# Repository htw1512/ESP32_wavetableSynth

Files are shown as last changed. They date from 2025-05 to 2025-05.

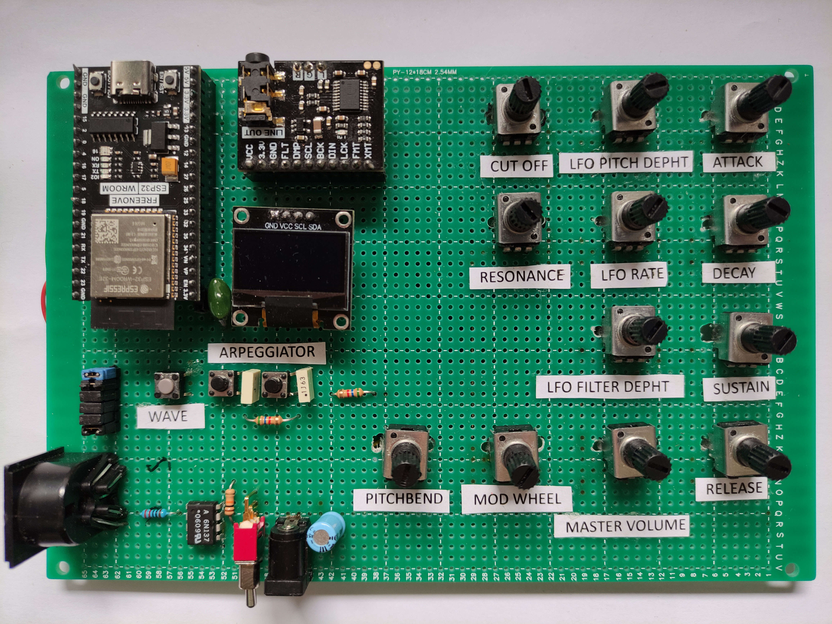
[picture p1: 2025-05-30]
Bilder/synth32.jpg

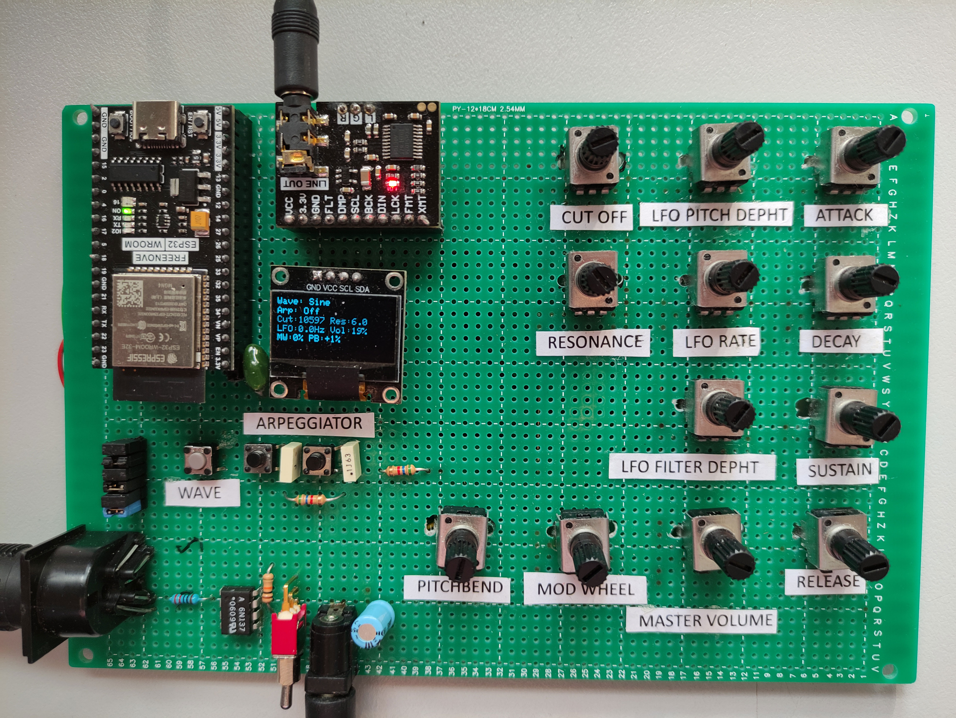
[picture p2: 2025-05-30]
Bilder/synth32_Betrieb.jpg

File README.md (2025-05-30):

# ESP32-S3 Polyphoner Wavetable-Synthesizer

Dieser vielseitige polyphone Synthesizer basiert auf dem ESP32-S3 Mikrocontroller und bietet eine breite Palette an Klangerzeugungsmöglichkeiten. Er verfügt über eine umfangreiche Sammlung an Wavetables, eine vollständige ADSR-Hüllkurve, ein State-Variable-Filter, einen modulierbaren LFO und einen komplexen Arpeggiator mit zahlreichen Modi, einschließlich Optionen für synchronisierte Tonika-Noten. Die Steuerung erfolgt über Potentiometer und Taster, mit visueller Rückmeldung über ein OLED-Display. MIDI-Eingabe wird über eine traditionelle 5-Pol-DIN-Buchse realisiert.

## Kernmodule des Synthesizers

*   **Oszillatoren**:
    *   Bis zu 51 verschiedene digital generierte Wellenformen pro Stimme.
    *   Auswahl umfasst klassische Formen (Sinus, Sägezahn, Rechteck, Dreieck), Pulsbreitenvarianten, Sync-Sounds, Formant-ähnliche Wellen und diverse experimentelle sowie perkussive und klavierähnliche Texturen.
    *   Auswahl der Wellenform über einen dedizierten Taster.
*   **Hüllkurve**:
    *   Eine ADSR-Hüllkurve (Attack, Decay, Sustain, Release) pro Stimme zur Formung der Lautstärke.
    *   Parameter steuerbar über dedizierte Potentiometer.
*   **Filter**:
    *   Ein globales State-Variable-Filter (SVF), dessen Tiefpass-Ausgang genutzt wird.
    *   Cutoff-Frequenz und Resonanz sind über Potentiometer regelbar.
*   **LFO (Low-Frequency Oscillator)**:
    *   Ein globaler LFO (Sinuswelle).
    *   Kann die Tonhöhe (Pitch) und/oder die Filter-Cutoff-Frequenz modulieren.
    *   LFO-Rate und die Modulationstiefe für Filter und Pitch (letztere oft in Kombination mit einem Modulationsrad-Poti) sind über Potentiometer einstellbar.
*   **Arpeggiator**:
    *   Umfangreicher Arpeggiator mit diversen Modi und Steuerungen:
        *   **Grund-Pattern**: Up, Down, Up/Down (mit korrekter Notenwiederholung), Random.
        *   **Oktav-Pattern**: Oct Up (spielt Pattern über mehrere Oktaven aufwärts), Oct Down (abwärts).
        *   **Chord-Modus**: Spielt alle gehaltenen Noten gleichzeitig im Arp-Rhythmus.
        *   **Played Order**: Spielt Noten in der Reihenfolge ihres Anschlags.
        *   **Geschwindigkeits-Modi**: Doppel- und Halbgeschwindigkeitsvarianten für Up, Down und Up/Down Pattern.
        *   **Tonika-Modi**: Varianten von Up, Down, Up/Down und Random, bei denen zusätzlich die tiefste gehaltene Note (Tonika) auf jedem Arp-Step mitgespielt wird.
    *   Steuerung über Taster für An/Aus und Moduswahl.
*   **MIDI-Eingang**:
    *   Empfang von MIDI-Daten (Note On, Note Off, Velocity) über eine traditionelle 5-Pol-DIN-Buchse, die über eine Optokoppler-Schaltung (6N137) an einen Hardware-Serial-Port des ESP32-S3 angebunden ist.
*   **Steuerung & Interaktion**:
    *   Analoge Potentiometer für Echtzeitkontrolle der meisten Syntheseparameter.
    *   Dedizierte Taster für Wellenformauswahl, Arp An/Aus und Arp-Moduswahl.
    *   Pitchbend- und Modulationsrad-Funktionalität über Potentiometer.
*   **Display**:
    *   0,96 Zoll OLED-Display (SSD1306-basiert, 128x64 Pixel) zur Anzeige der aktuellen Parameter, angebunden über I2C (SDA, SCL Pins).
*   **Audioausgabe**:
    *   Stereo-Audioausgabe über einen externen PCM5102A Digital-Analog-Wandler (DAC), der über die I2S-Schnittstelle des ESP32-S3 angesteuert wird.

## Hardware-Aufbau

*   **Mikrocontroller-Board**: Freenove ESP32-S3-WROOM-1 Development Board (oder ein vergleichbares ESP32-S3 Board).
*   **Digital-Analog-Wandler (DAC)**: PCM5102A I2S Stereo DAC-Modul für die Audioausgabe.
*   **MIDI-Eingang**:
    *   Standard 5-Pol-DIN-Buchse.
    *   Optokoppler-Schaltung mit einem 6N137 (oder äquivalent) zur galvanischen Trennung und Pegelanpassung des MIDI-Signals für den ESP32-S3 GPIO (typischerweise RX-Pin eines Hardware-UARTs).
*   **Display**:
    *   0,96 Zoll monochromes OLED-Display mit SSD1306 Controller.
    *   Auflösung: 128x64 Pixel.
    *   Anbindung über I2C-Bus (SDA- und SCL-Pins des ESP32-S3).
*   **Bedienelemente**:
    *   Diverse lineare Potentiometer (typischerweise 10k Ohm) für Parametersteuerung.
    *   Taster (Push Buttons) mit Pull-Up-Widerständen (intern oder extern) für Menü- und Funktionsauswahl.
*   **Stromversorgung**:
    *   Typischerweise über den USB-Anschluss des ESP32-S3 Boards oder
    *   Über ein externes Netzteil und einem Schalter ("Power-In Schalter") wird die 3.3V-Versorgung für das gesamte Board bereitgestellt.

## Konfigurationen & Performance

Der Synthesizer kann in zwei primären Konfigurationen betrieben werden, die einen Kompromiss zwischen Audioqualität/Polyphonie und CPU-Last darstellen:

### Version 1: "Lo-Fi / High Polyphonie" (Beispielkonfiguration)

*   **Sample Rate**: `22050 Hz`
*   **Aktive Stimmen (Polyphonie)**: `8 Stimmen`
*   **Charakteristik**: Diese Konfiguration ermöglicht eine höhere Anzahl gleichzeitig spielbarer Noten, was besonders für komplexe Akkorde oder dichte Arpeggios von Vorteil ist. Die niedrigere Sample Rate kann zu einem "Lo-Fi"-Charakter mit weniger Brillanz in den höchsten Frequenzen und potenziell mehr Aliasing bei sehr hohen Noten führen, was aber auch als klangästhetisches Merkmal geschätzt werden kann.

### Version 2: "Hi-Fi / Focused Polyphonie" (Aktuelle Konfiguration im Code)

*   **Sample Rate**: `44100 Hz`
*   **Aktive Stimmen (Polyphonie)**: `3 Stimmen`
*   **Charakteristik**: Bietet eine höhere Audioqualität mit besserer Abbildung hoher Frequenzen und weniger Aliasing-Artefakten. Die reduzierte Stimmenanzahl stellt sicher, dass die CPU-Last auch bei der höheren Sample Rate im Rahmen bleibt. Dies ist ideal für klarere Lead-Sounds, Bässe oder weniger dichte Arpeggios, bei denen die Klangqualität jeder einzelnen Note im Vordergrund steht. Bei den Arp-Modi mit Tonika (die 2 Stimmen pro Step benötigen) ist die effektive Polyphonie für ausklingende Noten weiter reduziert.

## Technische Basis

*   **Mikrocontroller**: ESP32-S3 (im Freenove Development Board)
*   **Programmierung**: Arduino Framework mit FreeRTOS für Multitasking.
*   **Wellenform-Speicher**: Intern generierte Wavetables im SRAM

  ## Hinweis zum Code Upload über die Arduino IDE
  * Die Auswahl des Boards in der Arduino IDE hängt von der Verwendung des jeweiligen ESP32Board ab.
  * in Abhängigkeit vom verwendeten Boards müssen beim Upload Verbindungen zu bestimmten Pins getrennt werden. im vorliegenden Fall wurde das über Jumper gelöst.

  ## Codegenerierung und Prüfung mit KI
  *Google Studio AI in der Gratisversion setzte die Anforderungen in Code um
  *Letztlich wurde eine spielbare Version erzeugt mit den oben benannten Merkmalen

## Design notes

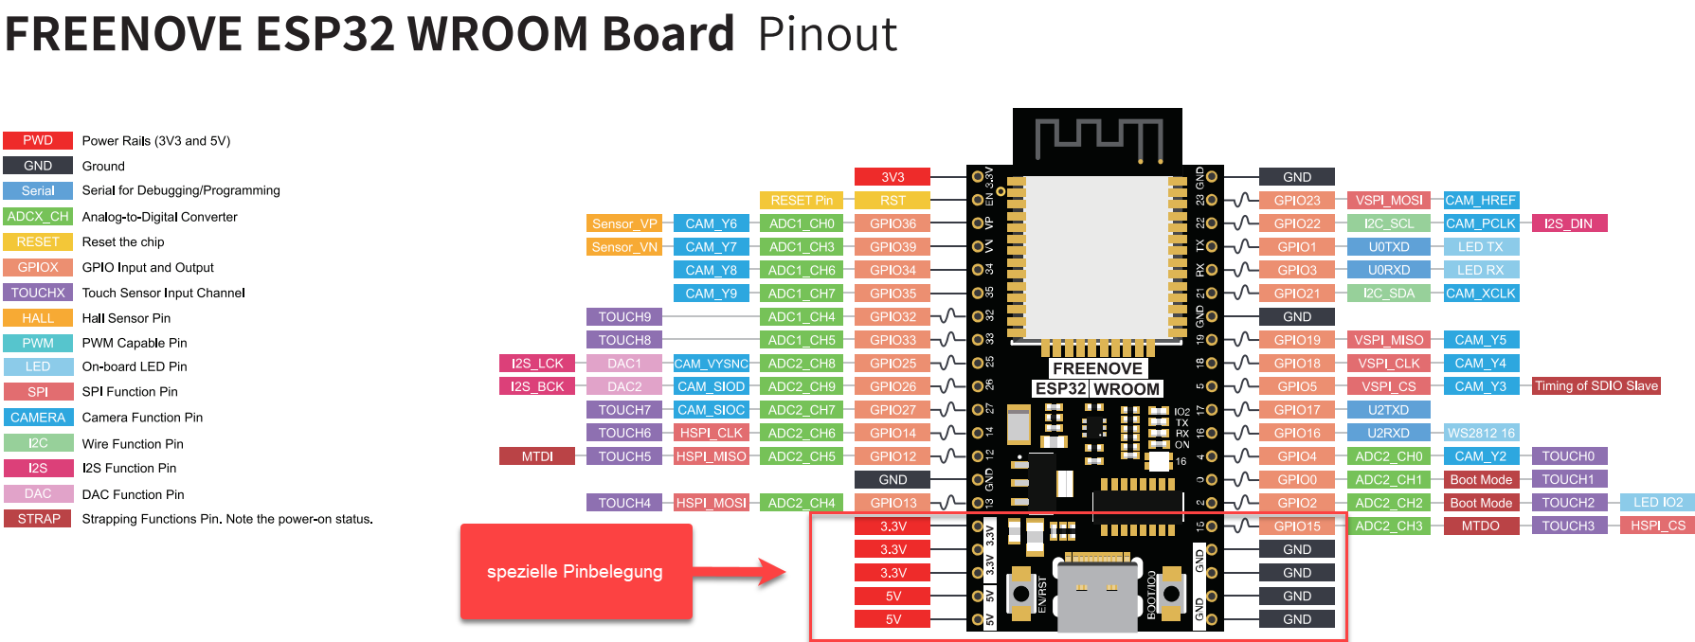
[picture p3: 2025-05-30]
Bilder/Freenove ESP32-S3 Pinbelegung.png

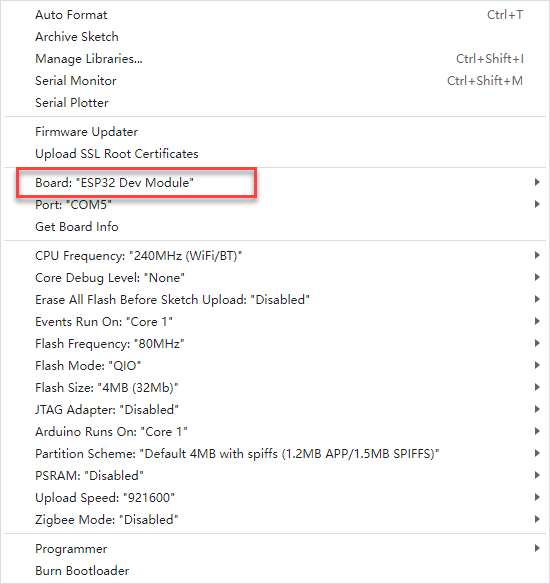
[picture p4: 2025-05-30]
Bilder/Arduino_Configuration.png

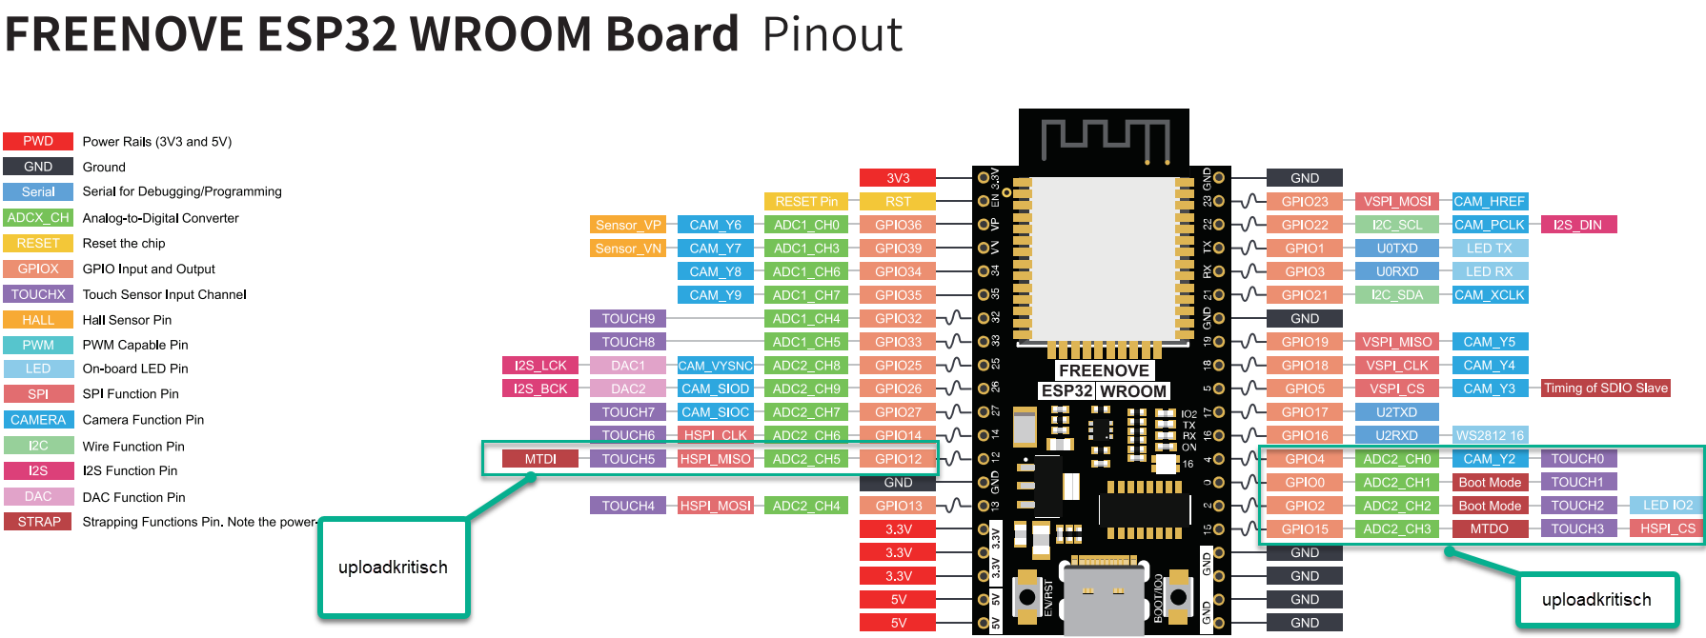
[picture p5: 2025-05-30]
Bilder/Freenove ESP32-S3 Pinbelegung_Upload.png

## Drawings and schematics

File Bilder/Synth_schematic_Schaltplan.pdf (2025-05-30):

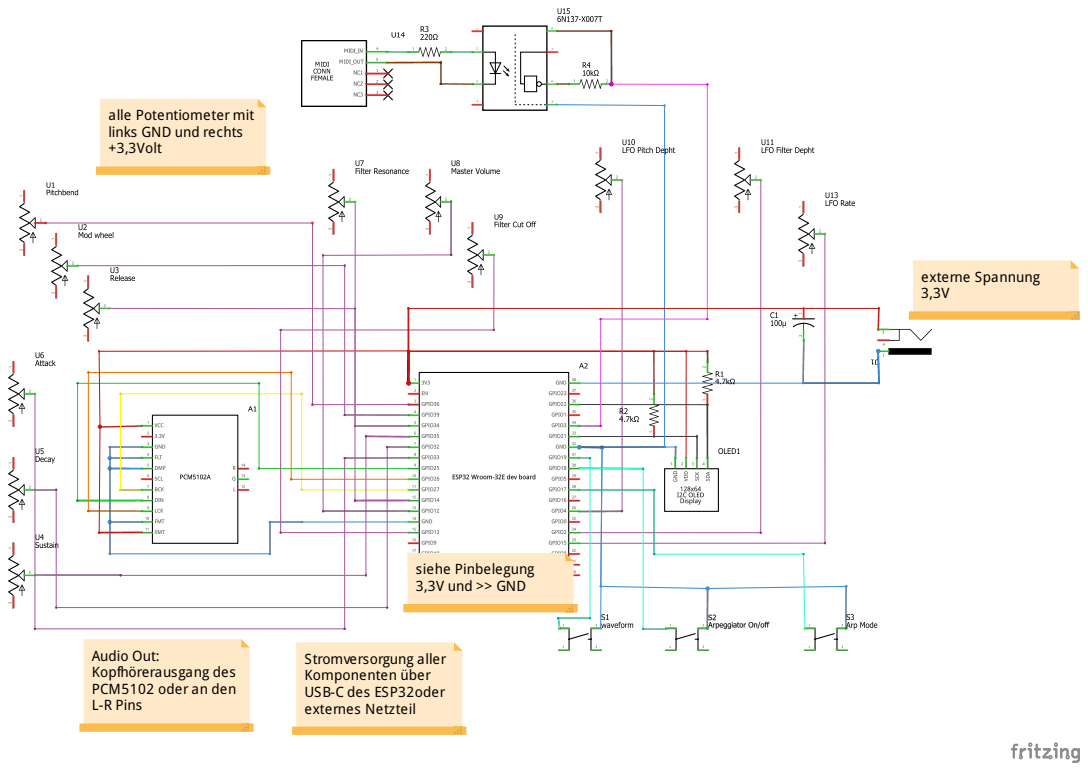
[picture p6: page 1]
Stromversorgung aller Komponenten über USB-C des ESP32oder externes Netzteil; siehe Pinbelegung 3,3V und >> GND; externe Spannung 3,3V

alle Potentiometer mit
links GND und rechts
+3,3Volt

Audio Out:
Kopfhörerausgang des
PCM5102 oder an den
L-R Pins

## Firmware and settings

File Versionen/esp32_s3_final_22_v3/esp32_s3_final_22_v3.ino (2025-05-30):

// ESP32-S3 - 6-VOICE POLYPHONIC SYNTH - (V34.1-ExtendedWaves - Original V34.0 + 35 New Waves)

// -----------------------------------------------------------------------------
// INCLUDES
// -----------------------------------------------------------------------------
#include <Arduino.h>
#include <driver/i2s_std.h>
#include <MIDI.h>
#include <math.h>
#include "freertos/FreeRTOS.h"
#include "freertos/task.h"
#include "freertos/semphr.h"
#include <Wire.h>
#include <Adafruit_GFX.h>
#include <Adafruit_SSD1306.h>

// -----------------------------------------------------------------------------
// KONSTANTEN & DEFINITIONEN
// -----------------------------------------------------------------------------
#define SAMPLE_RATE         44100 // Wie in deinem Code
#define NUM_CHANNELS        2
#define I2S_PORT_NUM        I2S_NUM_0
#define I2S_BCLK_PIN        (GPIO_NUM_27)
#define I2S_LRCK_PIN        (GPIO_NUM_26)
#define I2S_DOUT_PIN        (GPIO_NUM_25)
#define I2S_MCLK_PIN        (GPIO_NUM_NC)
#define DMA_BUFFER_COUNT    8
#define DMA_BUFFER_FRAMES   256
const int BYTES_PER_FRAME_STEREO = NUM_CHANNELS * (I2S_DATA_BIT_WIDTH_16BIT / 8);
const int I2S_WRITE_BUFFER_SIZE_BYTES = DMA_BUFFER_FRAMES * BYTES_PER_FRAME_STEREO;
const float MAX_SYSTEM_AMPLITUDE_FLOAT = 32760.0f;
#define MIDI_RX_PIN         GPIO_NUM_3
#define MIDI_TX_PIN_FOR_SERIAL2 GPIO_NUM_NC
#define MIDI_BAUD_RATE      31250
#define MIDI_LISTEN_CHANNEL MIDI_CHANNEL_OMNI

// --- Potis --- (unverändert)
#define POT_ATTACK_PIN      GPIO_NUM_33
#define POT_DECAY_PIN       GPIO_NUM_32
#define POT_SUSTAIN_PIN     GPIO_NUM_35
#define POT_RELEASE_PIN     GPIO_NUM_34
#define POT_FILTER_CUTOFF_PIN GPIO_NUM_13
#define POT_FILTER_RESO_PIN   GPIO_NUM_14
#define POT_LFO_RATE_PIN      GPIO_NUM_15
#define POT_LFO_PITCH_DEPTH_PIN GPIO_NUM_4
#define POT_LFO_FILTER_DEPTH_PIN GPIO_NUM_2
#define POT_MASTER_VOLUME_PIN   GPIO_NUM_12
#define POT_PITCHBEND_PIN       GPIO_NUM_36
#define POT_MOD_WHEEL_PIN       GPIO_NUM_39

// --- Taster --- (unverändert)
#define WAVE_SWITCH_PIN      GPIO_NUM_19
#define ARP_ONOFF_SWITCH_PIN GPIO_NUM_18
#define ARP_MODE_SWITCH_PIN  GPIO_NUM_17

// --- OLED Display --- (unverändert)
#define SCREEN_WIDTH 128
#define SCREEN_HEIGHT 64
#define OLED_RESET    -1
#define OLED_I2C_ADDRESS 0x3C

// --- Synthesizer Allgemein ---
#define NUM_VOICES_ACTIVE   3  // Wie in deinem Code
#define WAVETABLE_SIZE      256 // Wie in deinem Code

const float POLYPHONY_DAMPING_FACTOR = 4.0f; // Wie in deinem Code
const float PRE_FILTER_DRIVE_ATTENUATION = 0.5f; // Wie in deinem Code

// Originale Wellenform-defines
#define WAVE_SINE           0
#define WAVE_SAW_DOWN       1
#define WAVE_SQUARE         2
#define WAVE_TRIANGLE       3
#define WAVE_PULSE_25       4
#define WAVE_PULSE_12       5
#define WAVE_SYNC_SAW       6
#define WAVE_FORMANT_A_ORG  7 // Umbenannt, da "Formant A" auch in neuen Waves vorkommt
#define WAVE_RAMP_UP        8
#define WAVE_HOLLOW_SQ_ORG  9 // Umbenannt
#define WAVE_FORMANT_O_ORG 10 // Umbenannt

// Gesamtzahl der Wellenformen: 11 Original + 30 Neue + 5 Weiche = 46
#define NUM_WAVETABLES_TOTAL 46


// --- Arpeggiator --- (unverändert aus deinem Code)
enum ArpMode {
    ARP_UP, ARP_DOWN, ARP_UP_DOWN, ARP_RANDOM,
    ARP_OCT_UP, ARP_OCT_DOWN, ARP_CHORD, ARP_ORDER_PLAYED,
    ARP_UP_DOUBLE, ARP_DOWN_DOUBLE, ARP_UP_DOWN_DOUBLE,
    ARP_UP_HALF, ARP_DOWN_HALF, ARP_UP_DOWN_HALF,
    NUM_ARP_MODES_SELECTABLE
};
const char* arp_mode_names[NUM_ARP_MODES_SELECTABLE] = {
    "Up", "Down", "Up/Down", "Random",
    "Oct Up", "Oct Down", "Chord", "Played",
    "Up x2", "Down x2", "Up/Dn x2",
    "Up /2", "Down /2", "Up/Dn /2"
};
volatile ArpMode current_arp_mode = ARP_UP;
volatile bool arp_is_on = false;

#define ARP_MAX_NOTES 10
volatile uint8_t arp_held_notes[ARP_MAX_NOTES];
volatile uint8_t arp_notes_by_order[ARP_MAX_NOTES];
volatile int arp_num_held_notes = 0;
volatile int arp_num_played_order_notes = 0;
volatile int arp_current_note_index = 0;
volatile int arp_current_played_order_index = 0;
unsigned long last_arp_step_time = 0;
const unsigned long ARP_BASE_INTERVAL_MS = 150;
volatile unsigned long current_arp_interval_ms = ARP_BASE_INTERVAL_MS;
volatile uint8_t arp_last_played_note_value = 0;
volatile uint8_t arp_last_velocity = 0;
bool arp_up_down_direction_is_up = true;
int arp_octave_shift = 0;
const int ARP_MAX_OCTAVE_STEPS = 3;


enum EnvelopeStage { ENV_IDLE, ENV_ATTACK, ENV_DECAY, ENV_SUSTAIN, ENV_RELEASE };
struct VoiceState { // Unverändert aus deinem Code
  volatile bool note_on_trigger; volatile bool note_off_trigger;
  uint8_t note; float velocity_gain;
  bool is_playing;
  float phase_accumulator; float phase_increment;
  int current_wave_idx;
  EnvelopeStage env_stage; float env_level;
  float env_attack_rate; float env_decay_rate;
  float env_sustain_level_voice; float env_release_rate;
};

// -----------------------------------------------------------------------------
// GLOBALE VARIABLEN
// -----------------------------------------------------------------------------
i2s_chan_handle_t i2s_tx_chan;
int16_t i2s_audio_buffer[DMA_BUFFER_FRAMES * NUM_CHANNELS];
VoiceState voices[NUM_VOICES_ACTIVE];
MIDI_CREATE_INSTANCE(HardwareSerial, Serial2, MIDI);

// Array für ALLE Wellenformen
float wavetables[NUM_WAVETABLES_TOTAL][WAVETABLE_SIZE];
// Array für ALLE Wellenform-Namen
const char* wavetable_display_names[NUM_WAVETABLES_TOTAL];


unsigned long last_direct_pot_read_time = 0;
const unsigned long DIRECT_POT_READ_INTERVAL_MS = 20;
SemaphoreHandle_t voicesMutex = NULL;
TaskHandle_t audioMainTaskHandle = NULL;
TaskHandle_t controlMainTaskHandle = NULL;
Adafruit_SSD1306 display(SCREEN_WIDTH, SCREEN_HEIGHT, &Wire, OLED_RESET);
volatile bool display_update_needed = true;
volatile int global_osc_wave_select_idx = WAVE_SINE; // Startet mit der ersten (originalen) Sinuswelle
// Restliche globale Variablen unverändert aus deinem Code
volatile float global_pitchbend_factor = 1.0f;
volatile float global_attack_time_ms = 10.0f;
volatile float global_decay_time_ms = 50.0f;
volatile float global_sustain_level = 0.8f;
volatile float global_release_time_ms = 100.0f;
volatile float global_master_volume = 0.7f;
volatile float global_filter_cutoff_hz_target = 10000.0f;
volatile float smoothed_filter_cutoff_hz = 10000.0f;
const float CUTOFF_SMOOTHING_FACTOR = 0.05f;
volatile float global_filter_resonance_target = 0.707f;
volatile float smoothed_filter_resonance = 0.707f;
const float RESO_SMOOTHING_FACTOR = 0.08f;
volatile float global_lfo_rate_hz_target = 0.0f;
volatile float smoothed_lfo_rate_hz = 0.0f;
const float LFO_RATE_SMOOTHING_FACTOR = 0.1f;
volatile float global_lfo_pitch_depth_base_poti = 0.0f;
volatile float global_mod_wheel_value = 0.0f;
volatile float global_lfo_pitch_depth = 0.0f;
volatile float global_lfo_filter_depth = 0.0f;
float lfo_phase = 0.0f; float lfo_increment = 0.0f;
float global_filter_integrator1_state = 0.0f;
float global_filter_integrator2_state = 0.0f;
float global_filter_lp_output = 0.0f;
float global_filter_bp_output = 0.0f;
int raw_pot_attack, raw_pot_decay, raw_pot_sustain, raw_pot_release;
int raw_pot_filter_cutoff, raw_pot_filter_reso;
int raw_pot_lfo_rate, raw_pot_lfo_pitch_depth_poti_raw, raw_pot_lfo_filter_depth_raw;
int raw_pot_master_volume, raw_pot_mod_wheel, raw_pot_pitchbend;
const int LFO_PITCH_DEPTH_POTI_DEADZONE = 200;
const int LFO_RATE_POTI_DEADZONE = 200;
const int LFO_FILTER_DEPTH_POTI_DEADZONE = 200;
const int MOD_WHEEL_POTI_DEADZONE = 200;
const int PITCHBEND_POTI_DEADZONE_CENTER = 60;
const float MAX_PITCHBEND_SEMITONES = 2.0f;
const int MASTER_VOLUME_POTI_DEADZONE = 50;
unsigned long last_wave_switch_press_time = 0;
const unsigned long WAVE_SWITCH_DEBOUNCE_TIME = 200;
unsigned long last_arp_onoff_press_time = 0;
const unsigned long ARP_ONOFF_DEBOUNCE_TIME = 200;
unsigned long last_arp_mode_press_time = 0;
const unsigned long ARP_MODE_DEBOUNCE_TIME = 200;


// -----------------------------------------------------------------------------
// HILFSFUNKTIONEN
// -----------------------------------------------------------------------------
float midiNoteToFreq(uint8_t noteVal) { return 440.0f * powf(2.0f, (noteVal - 69.0f) / 12.0f); }
float interpolateWavetable(float table[WAVETABLE_SIZE], float index) { int i0 = (int)floorf(index); int i1 = (i0 + 1); float fraction = index - i0; i0 %= WAVETABLE_SIZE; if (i0 < 0) i0 += WAVETABLE_SIZE; i1 %= WAVETABLE_SIZE; if (i1 < 0) i1 += WAVETABLE_SIZE; return table[i0] * (1.0f - fraction) + table[i1] * fraction; }

void normalizeWavetable(int wave_idx) {
    if (wave_idx >= NUM_WAVETABLES_TOTAL) return; // Sicherheitscheck
    float max_abs_val = 0.0f;
    for (int i = 0; i < WAVETABLE_SIZE; ++i) {
        if (fabsf(wavetables[wave_idx][i]) > max_abs_val) {
            max_abs_val = fabsf(wavetables[wave_idx][i]);
        }
    }
    if (max_abs_val > 0.00001f) {
        for (int i = 0; i < WAVETABLE_SIZE; ++i) {
            wavetables[wave_idx][i] /= max_abs_val;
        }
    }
}

// --- ERWEITERTE WELLENFORMGENERIERUNG ---
void generateAllSynthWavetables() {
    for (int w = 0; w < NUM_WAVETABLES_TOTAL; ++w) {
        for (int i = 0; i < WAVETABLE_SIZE; ++i) wavetables[w][i] = 0.0f;
        wavetable_display_names[w] = "N/A"; // Default für nicht zugewiesene
    }

    int current_wave_gen_idx = 0;

    // Originale 11 Wellenformen (Index 0-10)
    if (current_wave_gen_idx < NUM_WAVETABLES_TOTAL) { for (int i = 0; i < WAVETABLE_SIZE; ++i) wavetables[current_wave_gen_idx][i] = sinf(2.0f * PI * (float)i / WAVETABLE_SIZE); wavetable_display_names[current_wave_gen_idx++] = "Sine"; }
    if (current_wave_gen_idx < NUM_WAVETABLES_TOTAL) { for (int i = 0; i < WAVETABLE_SIZE; ++i) wavetables[current_wave_gen_idx][i] = 1.0f - 2.0f * (float)i / WAVETABLE_SIZE; wavetable_display_names[current_wave_gen_idx++] = "Saw Down"; }
    if (current_wave_gen_idx < NUM_WAVETABLES_TOTAL) { for (int k = 1; k <= 15; k += 2) for (int i = 0; i < WAVETABLE_SIZE; ++i) wavetables[current_wave_gen_idx][i] += (1.0f/k)*sinf(2.0f*PI*k*(float)i/WAVETABLE_SIZE); normalizeWavetable(current_wave_gen_idx); wavetable_display_names[current_wave_gen_idx++] = "Square"; }
    if (current_wave_gen_idx < NUM_WAVETABLES_TOTAL) { for (int i = 0; i < WAVETABLE_SIZE; ++i) { float val = 2.0f*(float)i/WAVETABLE_SIZE; if(val > 1.0f) val=2.0f-val; wavetables[current_wave_gen_idx][i] = 2.0f*val-1.0f; } wavetable_display_names[current_wave_gen_idx++] = "Triangle"; }
    if (current_wave_gen_idx < NUM_WAVETABLES_TOTAL) { int pw=WAVETABLE_SIZE/4; for(int i=0;i<WAVETABLE_SIZE;++i) wavetables[current_wave_gen_idx][i]=(i<pw)?1.0f:-1.0f; wavetable_display_names[current_wave_gen_idx++] = "Pulse 25%"; }
    if (current_wave_gen_idx < NUM_WAVETABLES_TOTAL) { int pw=WAVETABLE_SIZE/8; for(int i=0;i<WAVETABLE_SIZE;++i) wavetables[current_wave_gen_idx][i]=(i<pw)?1.0f:-1.0f; wavetable_display_names[current_wave_gen_idx++] = "Pulse 12%"; }
    if (current_wave_gen_idx < NUM_WAVETABLES_TOTAL) { float mr=4.5f; for(int i=0;i<WAVETABLE_SIZE;++i){float p=(float)i/WAVETABLE_SIZE; float sp=fmod(p*mr,1.0f); wavetables[current_wave_gen_idx][i]=1.0f-2.0f*sp;} normalizeWavetable(current_wave_gen_idx); wavetable_display_names[current_wave_gen_idx++] = "Sync Saw"; }
    if (current_wave_gen_idx < NUM_WAVETABLES_TOTAL) { for(int i=0;i<WAVETABLE_SIZE;++i){float t=(float)i/WAVETABLE_SIZE; wavetables[current_wave_gen_idx][i]=0.5f*sinf(2*PI*t)+0.3f*sinf(2*PI*t*2.0f)+0.2f*sinf(2*PI*t*3.7f)+0.1f*sinf(2*PI*t*5.2f);} normalizeWavetable(current_wave_gen_idx); wavetable_display_names[current_wave_gen_idx++] = "Formant A"; } // Original Formant A
    if (current_wave_gen_idx < NUM_WAVETABLES_TOTAL) { for(int i=0;i<WAVETABLE_SIZE;++i) wavetables[current_wave_gen_idx][i]=-1.0f+2.0f*(float)i/WAVETABLE_SIZE; wavetable_display_names[current_wave_gen_idx++] = "Ramp Up"; }
    if (current_wave_gen_idx < NUM_WAVETABLES_TOTAL) { for(int i=0;i<WAVETABLE_SIZE;++i){float t=2*PI*(float)i/WAVETABLE_SIZE; wavetables[current_wave_gen_idx][i]=sinf(t)+(1.0f/3.0f)*sinf(3*t)+(1.0f/5.0f)*sinf(5*t);} normalizeWavetable(current_wave_gen_idx); wavetable_display_names[current_wave_gen_idx++] = "HollowSquare"; } // Original Hollow Square
    if (current_wave_gen_idx < NUM_WAVETABLES_TOTAL) { for(int i=0;i<WAVETABLE_SIZE;++i){float t=(float)i/WAVETABLE_SIZE; wavetables[current_wave_gen_idx][i]=0.6f*sinf(2*PI*t)+0.4f*sinf(2*PI*t*1.8f)+0.1f*sinf(2*PI*t*4.5f);} normalizeWavetable(current_wave_gen_idx); wavetable_display_names[current_wave_gen_idx++] = "Formant O"; } // Original Formant O
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
void loop() {
  vTaskDelay(pdMS_TO_TICKS(1000));
}

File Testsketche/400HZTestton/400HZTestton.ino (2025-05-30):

#include <Arduino.h>
#include <driver/i2s_std.h>
#include <math.h> // Für sinf

// --- I2S Audio Config ---
#define SAMPLE_RATE         22050 // Deine aktuelle Samplerate
#define NUM_CHANNELS        2     // Stereo, auch wenn wir Mono-Signal ausgeben
#define I2S_PORT_NUM        I2S_NUM_0
#define I2S_BCLK_PIN        (GPIO_NUM_27) // Dein I2S BCLK Pin
#define I2S_LRCK_PIN        (GPIO_NUM_26) // Dein I2S LRCK/WS Pin
#define I2S_DOUT_PIN        (GPIO_NUM_25) // Dein I2S Data Out Pin
#define I2S_MCLK_PIN        (GPIO_NUM_NC) // Master Clock nicht verwendet

#define DMA_BUFFER_FRAMES   256   // Größe des DMA Buffers in Frames
#define DMA_BUFFER_COUNT    8     // Anzahl der DMA Buffer

const int BYTES_PER_FRAME_STEREO = NUM_CHANNELS * (I2S_DATA_BIT_WIDTH_16BIT / 8);
const int I2S_WRITE_BUFFER_SIZE_BYTES = DMA_BUFFER_FRAMES * BYTES_PER_FRAME_STEREO;
const float MAX_AMPLITUDE_INT16 = 15000.0f; // Amplitude für den Sinuston (etwas unter max)

i2s_chan_handle_t i2s_tx_chan;
int16_t i2s_audio_buffer[DMA_BUFFER_FRAMES * NUM_CHANNELS];

// --- Sine Oscillator State ---
const float TARGET_FREQUENCY = 400.0f; // 400 Hz
const float AMPLITUDE = 0.5f;          // Amplitude (0.0 bis 1.0)
float phase_accumulator = 0.0f;
const float PI_2 = 2.0f * PI;

// --- Audio Buffer Fill ---
void fillSineWaveBuffer() {
  float phase_increment = (PI_2 * TARGET_FREQUENCY) / (float)SAMPLE_RATE;

  for (int frame = 0; frame < DMA_BUFFER_FRAMES; ++frame) {
    float sample_float = sinf(phase_accumulator) * AMPLITUDE;
    
    phase_accumulator += phase_increment;
    if (phase_accumulator >= PI_2) {
      phase_accumulator -= PI_2;
    }
    
    int16_t sample_int16 = (int16_t)(sample_float * MAX_AMPLITUDE_INT16);
    i2s_audio_buffer[frame * NUM_CHANNELS + 0] = sample_int16; // Links
    i2s_audio_buffer[frame * NUM_CHANNELS + 1] = sample_int16; // Rechts (gleiches Signal für Stereo)
  }

  size_t bytes_written;
  esp_err_t err = i2s_channel_write(i2s_tx_chan, i2s_audio_buffer, I2S_WRITE_BUFFER_SIZE_BYTES, &bytes_written, portMAX_DELAY);
  if (err != ESP_OK) {
    Serial.printf("I2S Write Error: %s\n", esp_err_to_name(err));
  }
  // if (bytes_written != I2S_WRITE_BUFFER_SIZE_BYTES) {
  //   Serial.println("I2S underrun or incomplete write?");
  // }
}

// --- Setup ---
void setup() {
  Serial.begin(115200);
  Serial.println("ESP32 I2S 400Hz Sine Wave Test");

  // I2S Init
  i2s_chan_config_t chan_cfg = {
    .id = I2S_PORT_NUM,
    .role = I2S_ROLE_MASTER,
    .dma_desc_num = DMA_BUFFER_COUNT,
    .dma_frame_num = DMA_BUFFER_FRAMES,
    .auto_clear = true,
  };
  esp_err_t err = i2s_new_channel(&chan_cfg, &i2s_tx_chan, NULL);
  if (err != ESP_OK) { Serial.printf("I2S Chan new Error: %s\n", esp_err_to_name(err)); while(1); }

  i2s_std_config_t std_cfg = {
    .clk_cfg = {
      .sample_rate_hz = SAMPLE_RATE,
      .clk_src = I2S_CLK_SRC_APLL, // Oder I2S_CLK_SRC_DEFAULT
      .mclk_multiple = I2S_MCLK_MULTIPLE_256 
    },
    .slot_cfg = I2S_STD_PHILIPS_SLOT_DEFAULT_CONFIG(I2S_DATA_BIT_WIDTH_16BIT, I2S_SLOT_MODE_STEREO),
    .gpio_cfg = {
      .mclk = I2S_MCLK_PIN, 
      .bclk = I2S_BCLK_PIN, 
      .ws = I2S_LRCK_PIN, 
      .dout = I2S_DOUT_PIN, 
      .din = GPIO_NUM_NC, // Nicht als Input verwendet
      .invert_flags = { .mclk_inv = false, .bclk_inv = false, .ws_inv = false, }
    }
  };
  err = i2s_channel_init_std_mode(i2s_tx_chan, &std_cfg);
  if (err != ESP_OK) { Serial.printf("I2S Std Init Error: %s\n", esp_err_to_name(err)); while(1); }
  
  err = i2s_channel_enable(i2s_tx_chan);
  if (err != ESP_OK) { Serial.printf("I2S Chan Enable Error: %s\n", esp_err_to_name(err)); while(1); }

  Serial.println("I2S Initialized. Playing 400Hz tone...");
}

// --- Loop ---
void loop() {
  fillSineWaveBuffer(); 
  // Kein Delay hier, da i2s_channel_write blockierend ist und das Timing vorgibt.
  // In einem komplexeren Sketch würde man FreeRTOS Tasks verwenden.
}

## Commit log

2025-05-20 Add files via upload
    final version of ESP32-S3 Synth
2025-05-23 Add files via upload
    Dieselben Funktionalitäten, aber nur 3 Stimmen mit SampleRate 44100Khz
2025-05-30 Update README.md
    Funktionserweiterungen oszi und arp
2025-05-30 Delete Synth_schematic.fzz
    Neuupload
    [Synth_schematic.fzz]
2025-05-30 Delete esp32_s3_synth_final_22.ino
    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
2025-05-30 Delete SampleRate_44100/esp32_s3_synth_final_v2_44.ino
    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
2025-05-30 Initialer Upload
    [Synth_schematic.fzz]
